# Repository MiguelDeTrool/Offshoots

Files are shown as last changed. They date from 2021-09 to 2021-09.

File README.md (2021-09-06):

# Offshoots
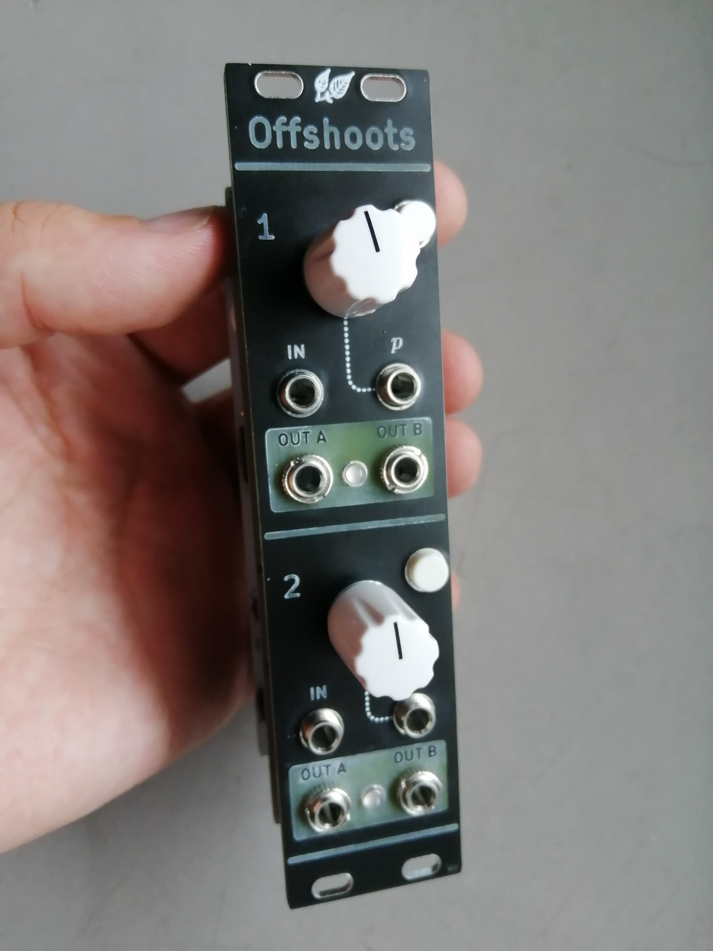
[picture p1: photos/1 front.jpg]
offshoots


Offshoots is an easy to DIY, Arduino Nano based adaptation of
[Mutable Instruments' Branches](https://mutable-instruments.net/modules/branches/). Heavily inspired by [sound-force.nl's Through-Hole Braids](https://sound-force.nl/?page_id=3179) and [Quinie.nl's NanoGris](https://github.com/Quinienl/NanoGris).

Only functional difference with Branches is Offshoots doesn't "remember" which output is high when leaving latch mode and coming back to it again. It needs a new input to latch to one of the outputs.

The photos included are of the prototype version of the board. I messed up the silkscreen, but that has been corrected. If you have some boards made, please send me photos! I also corrected a couple of other minor errors, so technically, this version of the board on github is untested, but I am very confident it works as intended.

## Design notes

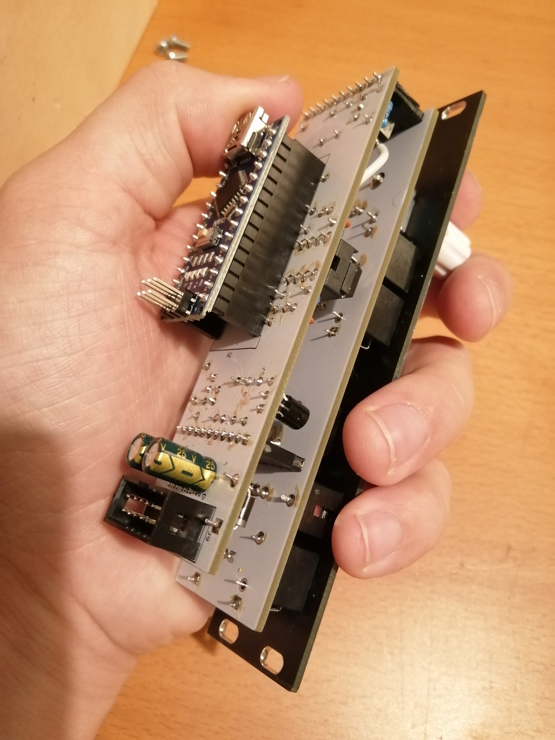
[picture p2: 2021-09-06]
photos/3 back.jpg

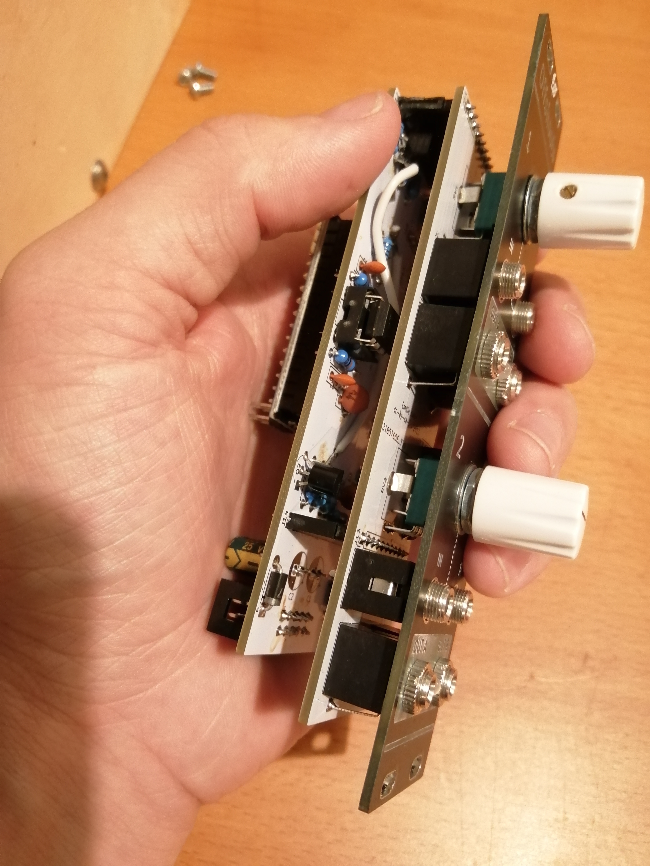
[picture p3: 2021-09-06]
photos/4 side.jpg

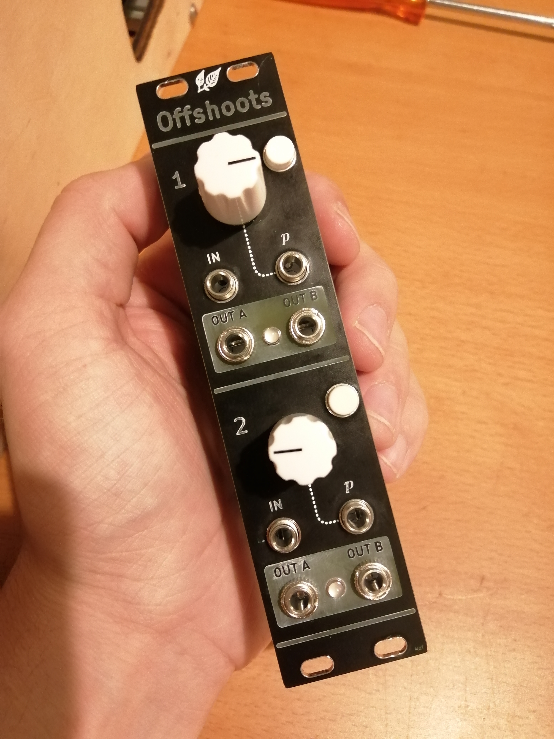
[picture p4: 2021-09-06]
photos/2 front.jpg

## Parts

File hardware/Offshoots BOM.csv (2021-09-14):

Designator | Package | Quantity | Designation | Tayda link, notes
J12,J14 | PinHeader_1x10_P2.54mm_Vertical | 2 | Conn_01x10_Female | https://www.taydaelectronics.com/40-pin-2-54-mm-single-row-female-pin-header.html
J11,J13 | PinHeader_1x10_P2.54mm_Vertical | 2 | Conn_01x10_Male | https://www.taydaelectronics.com/40-pin-2-54-mm-single-row-pin-header-strip.html
J10 | PinHeader_1x03_P2.54mm_Vertical | 1 | Conn_01x03_Male | same as previous, no need to order extra
J9 | IDC-Header_2x05_P2.54mm_Vertical | 1 | Conn_02x05_Odd_Even | https://www.taydaelectronics.com/10-pin-box-header-connector-2-54mm.html
D1,D2 | D_DO-41_SOD81_P7.62mm_Horizontal | 2 | 1N4001 | https://www.taydaelectronics.com/1n4001-diode-1a-50v.html
Q1,Q2 | TO-92L_Inline_Wide | 2 | 2N3904 | https://www.taydaelectronics.com/2n3904-npn-general-propose-transistor.html
R1,R2,R3,R4,R5,R6,R7,R9 | R_Axial_DIN0207_L6.3mm_D2.5mm_P7.62mm_Horizontal | 8 | 100K | https://www.taydaelectronics.com/10-x-resistor-100k-ohm-1-4w-1-metal-film-pkg-of-10.html
R32,R32,R33,R34,R35 | R_Axial_DIN0207_L6.3mm_D2.5mm_P10.16mm_Horizontal | 5 | 1K | https://www.taydaelectronics.com/10-x-resistor-1k-ohm-1-4w-1-metal-film-pkg-of-10.html
R11,R12 | R_Axial_DIN0207_L6.3mm_D2.5mm_P10.16mm_Horizontal | 2 | 220R | https://www.taydaelectronics.com/resistor-220-ohm-1-4w-1-metal-film-pkg-of-10.html
R10 | R_Axial_DIN0207_L6.3mm_D2.5mm_P10.16mm_Horizontal | 1 | 5,1K | https://www.taydaelectronics.com/resistor-5-1k-ohm-1-4w-1-metal-film-pkg-of-10.html
C5,C6 | C_Disc_D5.0mm_W2.5mm_P2.50mm | 2 | 1nF ceramic | https://www.taydaelectronics.com/10-1nf-50v-ceramic-disc-capacitor.html
C3,C4 | C_Disc_D5.0mm_W2.5mm_P2.50mm | 2 | 100nF ceramic | https://www.taydaelectronics.com/a-553-0-1uf-50v-ceramic-disc-capacitor-pkg-of-10.html
C1,C2 | CP_Radial_D6.3mm_P2.50mm | 2 | 10uF electrolytic | https://www.taydaelectronics.com/10uf-35v-105c-radial-electrolytic-capacitor-5x11mm.html
U4 | TO-92L_Inline_Wide | 1 | LM4040LP-5 (or 10V Zener, see notes) | https://www.taydaelectronics.com/1n4740a-1n4740-zener-diode-10v-1w.html
U3 | DIP-8_W7.62mm_LongPads | 1 | MCP6002-xP | NOT AVAILABLE from tayda. I may make another version that uses non rail-to-rail op-amps, like MCP602 or LM358. If you use them in current design you don’t get the full pot range
SW1,SW2 | DPDT_Momentary_Push_Button_Switch | 2 | SW_Push_DPDT_Latching | https://www.taydaelectronics.com/push-button-switch-latching-dpdt-0-5a-50vdc-6x6mm.html
RV1,RV2 | Potentiometer | 2 | R_POT 10k | https://www.taydaelectronics.com/tayda-10k-ohm-linear-taper-potentiometer-spline-shaft-pcb-mount-9mm.html
J1,J2,J3,J4,J5,J6,J7,J8 | Thonkiconn | 8 | Jack | https://www.taydaelectronics.com/pj-3001f-3-5-mm-mono-phone-jack.html
LED1,LED2 | LED_D3.0mm | 2 | LED_Bicolor_2pin | https://www.taydaelectronics.com/bi-color-led-3mm-red-green.html
A1 | Arduino_Nano | 1 | Arduino_Nano | https://www.taydaelectronics.com/nano-3-0-controller-compatible-with-arduino-nano-ch340-usb-driver.html Out of stock currently at tayda, but available from many places
EXTRAS | PinHeader_1x15_P2.54mm_Vertical | 2 | Headers for Arduino Nano | https://www.taydaelectronics.com/15-pin-2-54-mm-single-row-female-pin-header.html
 | Push Button Switch Caps White Color 6x5mm | 2 | Button Caps | https://www.taydaelectronics.com/push-button-switch-caps-white-color-6-x-5-mm.html
 | Knob DAVIES 1900H CLONE White | 2 | Knobs for pots | https://www.taydaelectronics.com/knob-davies-1900h-clone-white.html
 | Mini Jumper 2.54mm Gold Plated Closed Cover | 1 | Jumper for auto-gate config | https://www.taydaelectronics.com/mini-jumper-2-54mm-gold-plated-closed-cover.html OR https://www.taydaelectronics.com/mini-jumper-2-00mm-gold-plated-closed-cover.html
 | 8 pin DIP IC Socket Adaptor Solder Type | 1 | Socket for MCP6002 | https://www.taydaelectronics.com/8-pin-dip-ic-socket-adaptor-solder-type.html
NOTES |  |  |  | Total cost of Tayda cart with the Arduino is about $10, without it’s about $6,3. CHEAP!
 |  |  |  | The amount needed for tayda ordering may differ, ex: you only need to order one 40 pin header strip and cut to right sizes
 |  |  |  | You may have to experiment with lower values for R10, until you get -5V at the anode (pin 3) of the LM4040
 |  |  |  | You can replace the expensive and hard to source LM4040LP-5 with a 10V Zener, you just have to replace R3 and R6 with 200k resistors. The Zener and resistors and 14 cents to the cart
 |  |  |  | LED orientation isn’t vital so long as it’s consistent. Use LED orientation indicated on PCB (shorter lead to square pad) to have original Branches colors
 |  |  |  | Switch orientation isn’t vital so long as it’s consistent. Just changes which mode corresponds to pushed/unpushed position
 |  |  |  | You could just use 1K resistors for R11 and R12, it would save ordering extra 220R ones. It just makes LEDs slightly duller
 |  |  |  | You can get two 6mm M3 screws and a 11mm M3 standoff to hold the control and brain boars together, but I don’t find them necessary
 |  |  |  | Auto-gate generation isn’t implemented yet, might never be

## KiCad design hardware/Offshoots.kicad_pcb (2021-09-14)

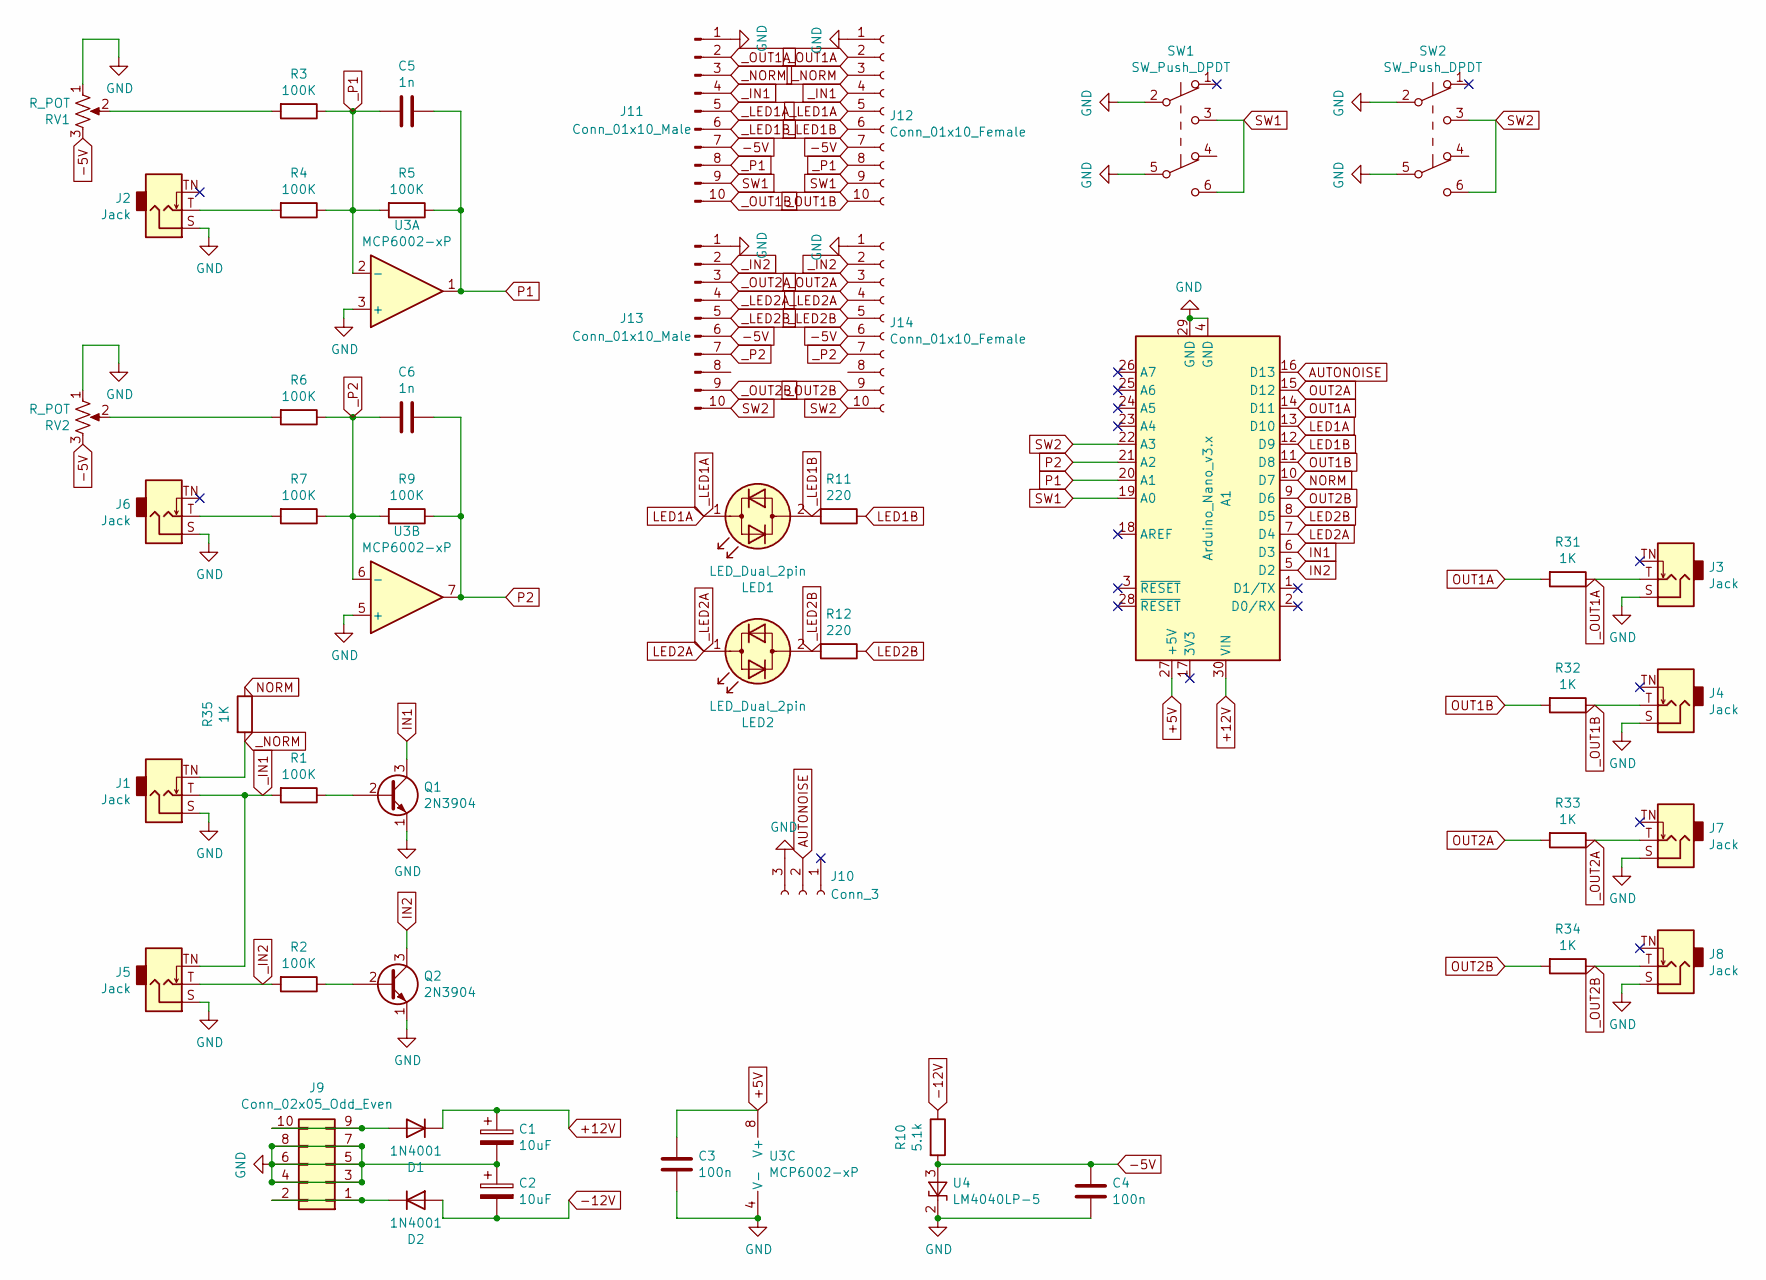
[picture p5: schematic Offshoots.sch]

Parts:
A1: Arduino_Nano_v3.x; Arduino_Nano
C1, C2: 10uF; CP_Radial_D6.3mm_P2.50mm
C3, C4: 100n; C_Disc_D5.0mm_W2.5mm_P2.50mm
C5, C6: 1n; C_Disc_D5.0mm_W2.5mm_P2.50mm
D1, D2: 1N4001; D_DO-41_SOD81_P7.62mm_Horizontal
J1, J2, J3, J4, J5, J6, J7, J8: Jack; ModdedThonkiconn
J9: Conn_02x05_Odd_Even; IDC-Header_2x05_P2.54mm_Vertical
J10: Conn_3; PinHeader_1x03_P2.54mm_Vertical
J11, J13: Conn_01x10_Male; PinHeader_1x10_P2.54mm_Vertical
J12, J14: Conn_01x10_Female; PinHeader_1x10_P2.54mm_Vertical
LED1, LED2: LED_Dual_2pin; LED_D3.0mm
Q1, Q2: 2N3904; TO-92L_Inline_Wide
R1, R2, R3, R4, R5, R6, R7, R9: 100K; R_Axial_DIN0207_L6.3mm_D2.5mm_P7.62mm_Horizontal
R10: 5.1k; R_Axial_DIN0207_L6.3mm_D2.5mm_P7.62mm_Horizontal
R11, R12: 220; R_Axial_DIN0207_L6.3mm_D2.5mm_P7.62mm_Horizontal
R31, R32, R33, R34, R35: 1K; R_Axial_DIN0207_L6.3mm_D2.5mm_P7.62mm_Horizontal
RV1, RV2: R_POT; ModdedPotentiometer
SW1, SW2: SW_Push_DPDT; DPDT_Momentary_Push_Button_Switch
U3: MCP6002-xP; DIP-8_W7.62mm_LongPads
U4: LM4040LP-5; TO-92L_Inline_Wide

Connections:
+5V: A1.27 (+5V), C3.2, U3.8 (V+)
+12V: A1.30 (VIN), C1.1, D1.1 (K)
-5V: C4.2, J11.7, J12.7, J13.6, J14.6, R10.2, RV1.3, RV2.3, U4.3 (A)
-12V: C2.2, D2.2 (A), R10.1
AUTONOISE: A1.16 (D13), J10.2
GND: A1.4 (GND), A1.29 (GND), C1.2, C2.1, C3.1, C4.1, J1.S, J2.S, J3.S, J4.S, J5.S, J6.S, J7.S, J8.S, J9.3, J9.4, J9.5, J9.6, J9.7, J9.8, J10.3, J11.1, J12.1, J13.1, J14.1, Q1.1 (E), Q2.1 (E), RV1.1, RV2.1, SW1.2 (B), SW1.5 (B), SW2.2 (B), SW2.5 (B), U3.3 (+), U3.4 (V-), U3.5 (+), U4.2 (K)
IN1: A1.6 (D3), Q1.3 (C)
IN2: A1.5 (D2), Q2.3 (C)
LED1A: A1.13 (D10), J11.5, J12.5, LED1.1 (KA)
LED1B: A1.12 (D9), R11.1
LED2A: A1.7 (D4), J13.4, J14.4, LED2.1 (KA)
LED2B: A1.8 (D5), R12.1
NORM: A1.10 (D7), R35.1
unnamed: D1.2 (A), J9.9, J9.10
unnamed: D2.1 (K), J9.1, J9.2
unnamed: J2.T, R4.2
unnamed: J6.T, R7.2
unnamed: Q1.2 (B), R1.1
unnamed: Q2.2 (B), R2.1
unnamed: R3.2, RV1.2
unnamed: R6.2, RV2.2
OUT1A: A1.14 (D11), R31.2
OUT1B: A1.11 (D8), R32.2
OUT2A: A1.15 (D12), R33.2
OUT2B: A1.9 (D6), R34.2
P1: A1.20 (A1), C5.1, R5.1, U3.1
P2: A1.21 (A2), C6.1, R9.1, U3.7
SW1: A1.19 (A0), J11.9, J12.9, SW1.3 (C), SW1.6 (C)
SW2: A1.22 (A3), J13.10, J14.10, SW2.3 (C), SW2.6 (C)
_IN1: J1.T, J5.TN, J11.4, J12.4, R1.2
_IN2: J5.T, J13.2, J14.2, R2.2
_LED1B: J11.6, J12.6, LED1.2 (AK), R11.2
_LED2B: J13.5, J14.5, LED2.2 (AK), R12.2
_NORM: J1.TN, J11.3, J12.3, R35.2
_OUT1A: J3.T, J11.2, J12.2, R31.1
_OUT1B: J4.T, J11.10, J12.10, R32.1
_OUT2A: J7.T, J13.3, J14.3, R33.1
_OUT2B: J8.T, J13.9, J14.9, R34.1
_P1: C5.2, J11.8, J12.8, R3.1, R4.1, R5.2, U3.2 (-)
_P2: C6.2, J13.7, J14.7, R6.1, R7.1, R9.2, U3.6 (-)

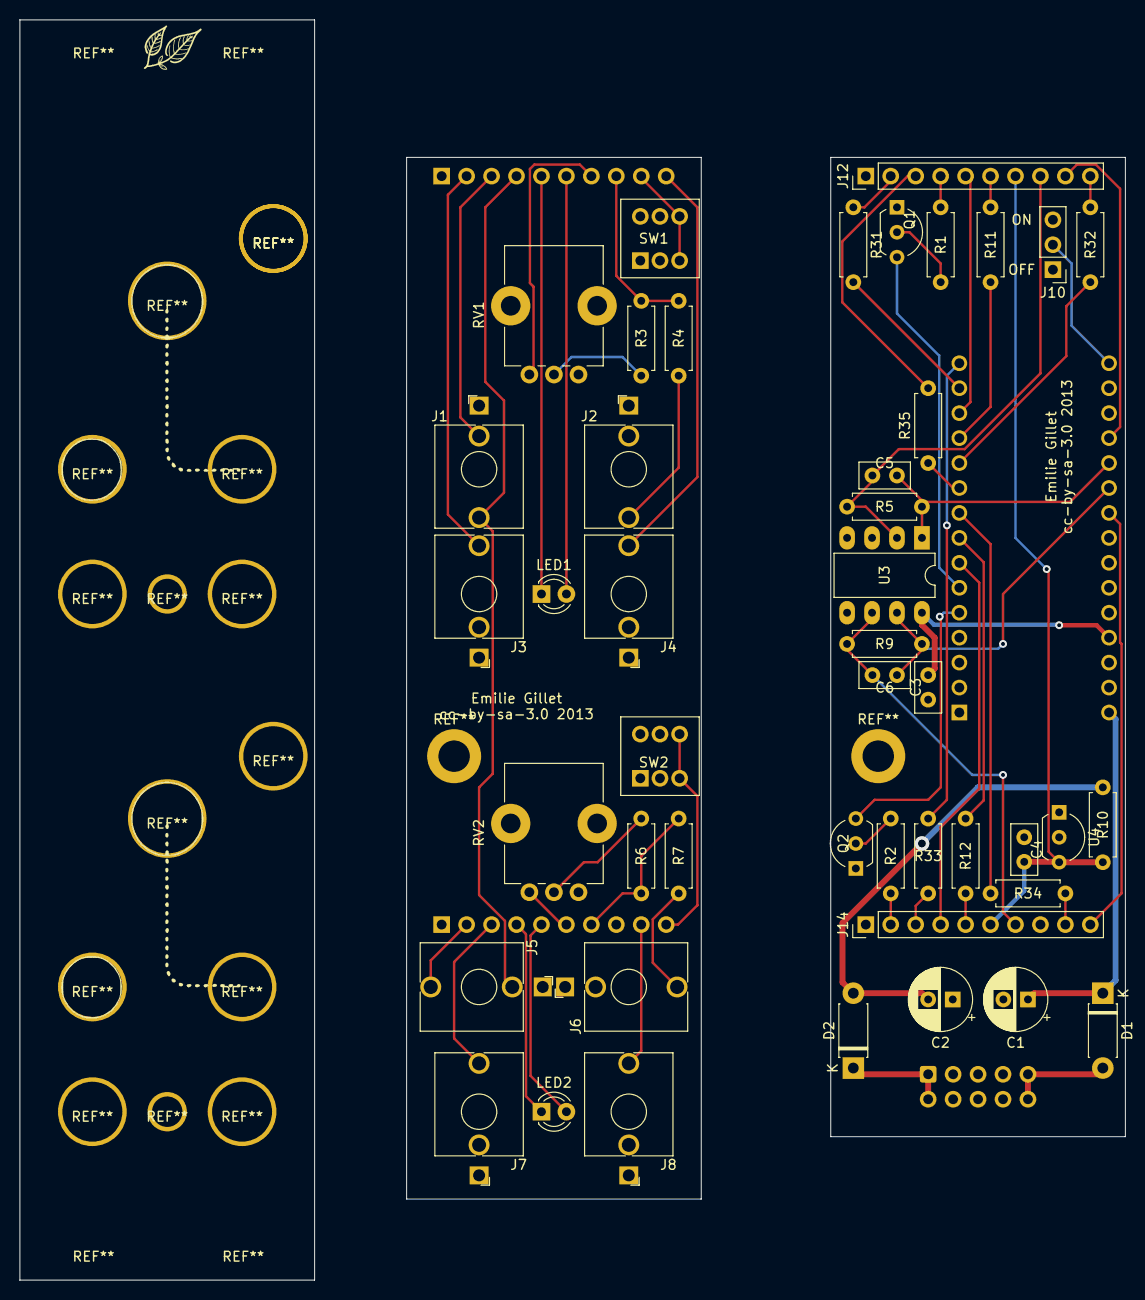
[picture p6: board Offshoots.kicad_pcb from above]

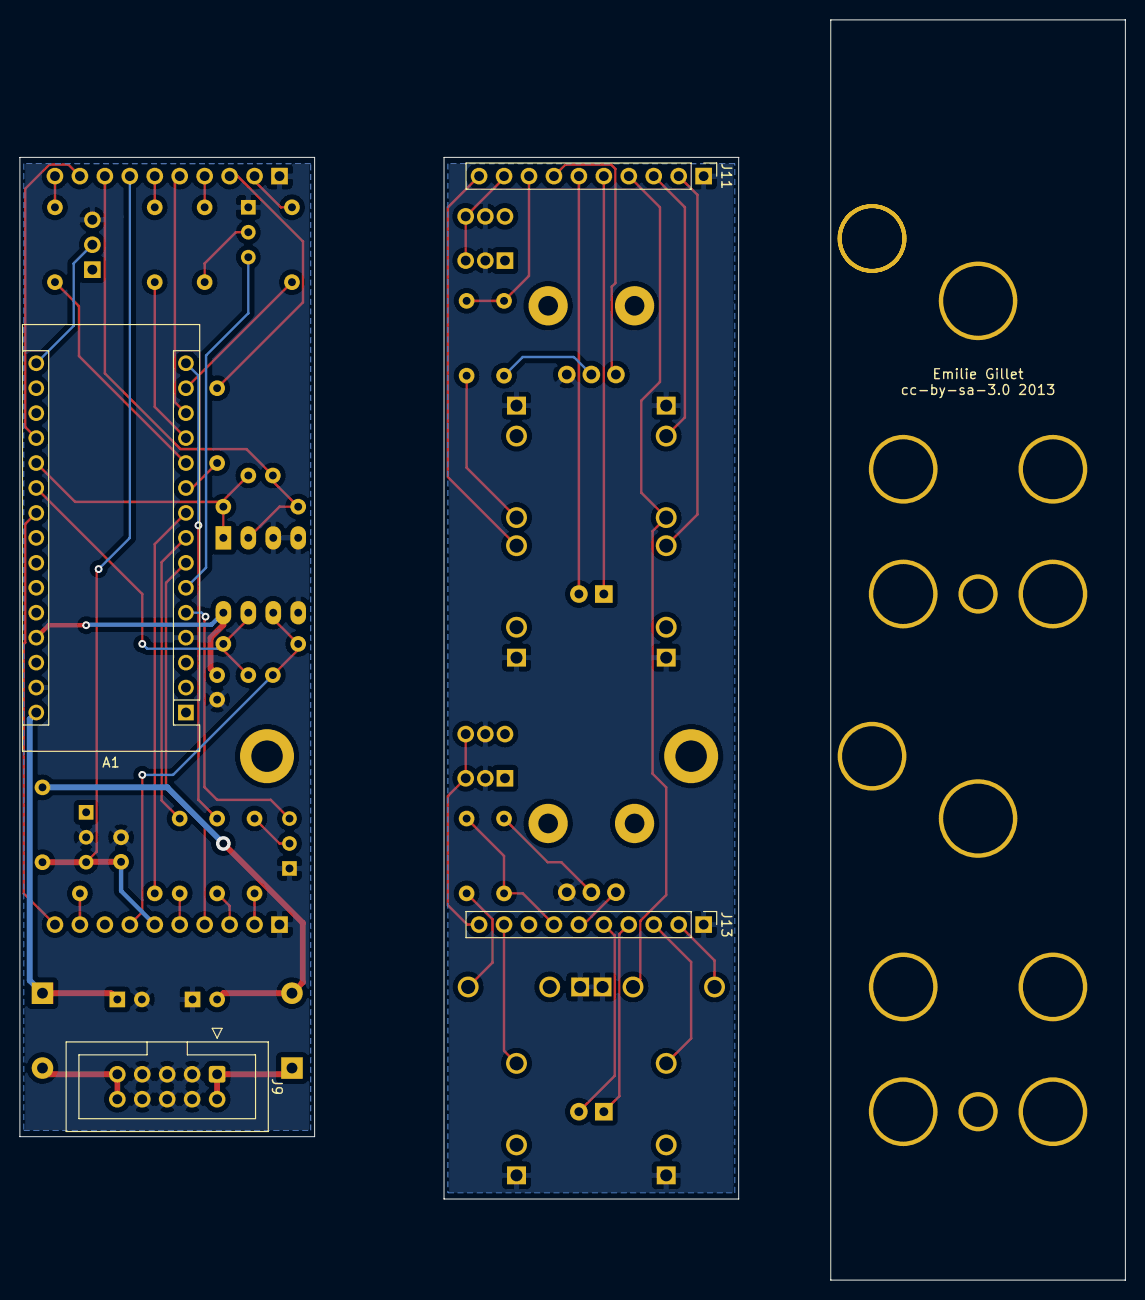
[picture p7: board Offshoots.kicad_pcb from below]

Board: 2 copper layers, 112.6 x 128.3 mm, 49 parts (4 on the bottom side), 40 nets.

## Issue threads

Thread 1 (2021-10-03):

Compatibility with original branch panel?

zerbian, 2021-10-03:
Hey there, I recently discovered this repo and was wondering if this diy clone is compatible with the original board design. Can I use the original panel with the pcbs ?

Thank you!

MiguelDeTrool, 2021-10-04:
Hello! It might just fit into to an original panel, but I wouldn't recommend it. The jacks would be slightly wonky, as they are a bit more spaced out horizontally on the original. Also, the button diameter is slightly different. I use 6mm, the original uses 5mm. You would have to either find different button caps, which wouldn't be easy, or drill the original panel a slight bit.

zerbian, 2021-10-04:
Okay, thank you, good to know!

Closed 2021-10-04.

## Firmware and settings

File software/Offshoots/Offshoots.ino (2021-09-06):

// Copyright 2021 migueldetrool
//
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
// Auto gate generation not yet implemented

//pin associations
int in[] = {3, 2}; //switch with wires
int p[] = {A1, A2};
int outA[] = {11, 12}; //switch with wires
int LEDA[] = {10, 4};
int outB[] = {8, 6};
int LEDB[] = {9, 5};
int mode[] = {A0, A3};
bool cointoss[] = {false, false};
bool latchState[] = {false, false};

void setup() {
  // pins for 1st channel
  pinMode(in[0], INPUT_PULLUP);
  pinMode(p[0], INPUT);
  pinMode(mode[0], INPUT_PULLUP);
  pinMode(outA[0], OUTPUT);
  pinMode(outB[0], OUTPUT);
  pinMode(LEDA[0], OUTPUT);
  pinMode(LEDB[0], OUTPUT);
  

  // pins for 2nd channel
  pinMode(in[1], INPUT_PULLUP);
  pinMode(p[1], INPUT);
  pinMode(mode[1], INPUT_PULLUP);
  pinMode(outA[1], OUTPUT);
  pinMode(outB[1], OUTPUT);
  pinMode(LEDA[1], OUTPUT);
  pinMode(LEDB[1], OUTPUT);

  attachInterrupt(digitalPinToInterrupt(in[0]), change0, CHANGE);
  attachInterrupt(digitalPinToInterrupt(in[1]), change1, CHANGE);
  

}

void change0() {
  if (digitalRead(mode[0]) == HIGH) {
    toggleLogic(0);
  }
  else {
    latchLogic(0);
  }
}

void change1() {
  if (digitalRead(mode[1]) == HIGH) {
    toggleLogic(1);
  }
  else {
    latchLogic(1);
  }
}

void toggleLogic(int channel) {
  if (digitalRead(in[channel]) == HIGH) {
    digitalWrite(outA[channel], LOW);
    digitalWrite(outB[channel], LOW);
    digitalWrite(LEDA[channel], LOW);
    digitalWrite(LEDB[channel], LOW);
  }
  else {
    cointoss[channel] = random(1009) > analogRead(p[channel]);
    digitalWrite(outA[channel], !cointoss[channel]);
    digitalWrite(outB[channel], cointoss[channel]);
    digitalWrite(LEDA[channel], cointoss[channel]);
    digitalWrite(LEDB[channel], !cointoss[channel]);
  }
}

void latchLogic(int channel) {
  if (digitalRead(in[channel]) == LOW) {
    cointoss[channel] = random(1023) > analogRead(p[channel]);
    if (cointoss[channel] == true) {
      latchState[channel] = !latchState[channel];
    }
    digitalWrite(outA[channel], !latchState[channel]);
    digitalWrite(outB[channel], latchState[channel]);
    digitalWrite(LEDA[channel], latchState[channel]);
    digitalWrite(LEDB[channel], !latchState[channel]);
  }
}

void loop() {
  _NOP();
}

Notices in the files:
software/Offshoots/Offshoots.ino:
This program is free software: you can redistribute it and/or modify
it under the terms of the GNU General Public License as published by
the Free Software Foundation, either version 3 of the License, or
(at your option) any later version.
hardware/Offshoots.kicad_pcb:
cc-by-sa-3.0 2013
